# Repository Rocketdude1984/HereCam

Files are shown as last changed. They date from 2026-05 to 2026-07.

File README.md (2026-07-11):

# HereCam (WIP)
A camera for making yearly timelapses of a single room. Uses a Pi zero 2w, camera, and UPS hat. Inspired by the movie _Here_ (2024).

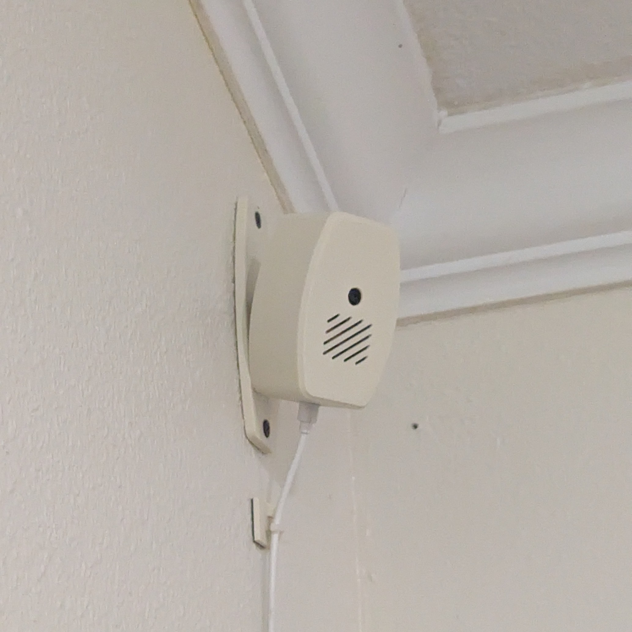
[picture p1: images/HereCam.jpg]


## Goals
- [x] Create a device that takes a picture at set intervals over the course of a year.
- [x] Store images on an SD card or SSD with easy removal.
- [x] Set up nightly automated backups to external server over wifi.
- [x] Be able to compile a years worth of images into a single timeplapse video
- [x] The timeplapse must have a reasonable play time (<1hr) and good quality.
- [ ] Must be able to operate without AC power for at least 12 hrs.
- [ ] Under $300 (2026 USD)

## Components
- Raspberry Pi Zero 2W - small form factor, wireless, enough processing power for timelapse compilation and image capture, and sd card slot.
- 75° Pi Camera module - FOV should be wide enough for being in the corner of a room, with IR filter.
- UPS hat - back-up power for when the device is unplugged, uses a lipo battery.
- SD card - capable of containing Pi OS and room for images, highly reliable card.
- Wall adapter - 5v slim form factor wall adapter
(see BOM for details of all components)

## Calculations

### 1. Length of Timelapse and number of images
   The first step was to find out how long I would want the timplapse to be and the framerate of the movie, which would also tell me the number of images that would be taken each year. I knew I did not want to capture images of every single hour, because the room I would be mounting the camera would have no one in it late at night (a living room). So I went with 20 hours per day (6am-2am). I also knew I wanted at least 24fps.
   
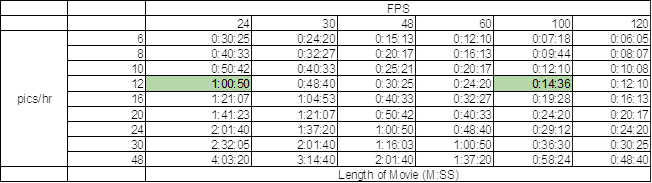
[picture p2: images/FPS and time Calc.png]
   

   I ended up liking two durations at 12 pics per hour (one image every 5 mins). This would give me a total of 87600 images/year. I liked the option of having a short timelapse (about 15 minutes and a longer at about 1 hour). The FPS of the short timelapse would be 100fps and the longer would be 24fps.
   
### 2. Storage size requirements
Now that I knew how many images I would have to store, I needed to calculate which resolution I would desire for a good quality video, yet not having a huge storage requirement. I was aiming for less than 256GB of images per year. I took pictures on my phone at 3 different resolutions and jpeg qualities. 1920x1080, 1920x1440, and 3840x2160 at 80%, 90%, and 100% (I ended up also trying 92% for the 3840x2160 resolution). I found that both the 1920x1080 and 1920x1440 resolutions did not look near crisp enough for my taste, so I stuck with the 3840x2160 resolution. JPEG compression somewhat works based on the actual image, so my test were done in about the expected positions that I would possibly mount the camera and then averaged together for a file average image size. The table below shows the final average values in KB for each image and in GB for the total 87600 images.

   

   All the 100% compression rates sizes were larger than I was wanting, but 90% and even 92% for the 3840x2160 was well under the 256GB I was wanting (the OS will eat up some of the SD card, will have to keep that in mind). I had at first picked the 90% compression, but ended up lowering it to 85% which images average 726KB, so about 61GB per year of images.

### 3. Runtime on Battery
Once I got the UPS hat and batteries in (a 1000mAh and 2000mAh), I did some ran a demo script that measures the power being used from the battery to run the pi. While idle the pi drew about 185mA from the battery and while taking a picture the pi drew about 400mA but only for about 2 seconds. Using these values I calculated the estimated runtime for the system. The 1000mAh battery would last about 6 hours while the 2000mAh would run about 11.8 hours. I then ran 2 tests to measure the actual runtime for each battery. For these test I ran a cron script to take an image every 5 minutes and name the file the number of the total images taken. This way I could moniter the battery voltage with the demo script and see when the voltage drops to 3.0 volts (voltage when BMS on the cell cuts off). I could then multiply the number of images taken by 5 minutes to get a total runtime. The calculated and actual values are below.

   

The 2000mAh lipo is still somewhat short of 12 hrs and this runtime will only decrease, but considering the size of the the device, I do not think I can increase the lipo much more. 

## Development
I designed and 3D printed several different housing and mounting systems for the camera. My first 2 designs used a mounting system that screwed into the corner of a room, but I later changed to a 2-axis mounting system that could mount on any way, just in case in the future I put the camera not in a corner. The later designs also included a vent for heat from the Pi.

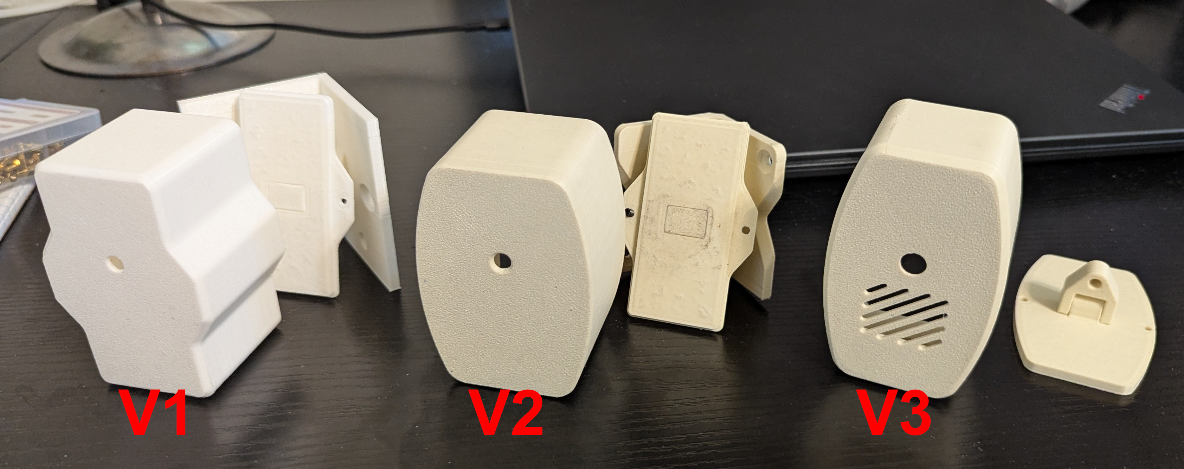
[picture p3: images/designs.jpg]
   

See the parts folder for 3D files.

## Construction

Two heat threaded inserts (2mm) and 2, 2mm socket head screws are used to mount the camera module in place. The pi/UPS modules are mounted with brass standoffs, and those standoffs are held in hexagonal pockets in the housing with JB weld. The lid to the housing is held in using 3mm heat threaded inserts and socket head screws. The mount uses 4mm socket head screws with nuts and washers to allow the camera to pivot on the 2 axes. The whole mount is fasten to the wall with regular 1-5/8" drywall screws. 

I had a lot of issues with the pogo pins of the UPS hat not aligning with the Pi's pads. To fix this I solderd the pads that contact the pogo connectors and this fixed all the issues. See the image below.

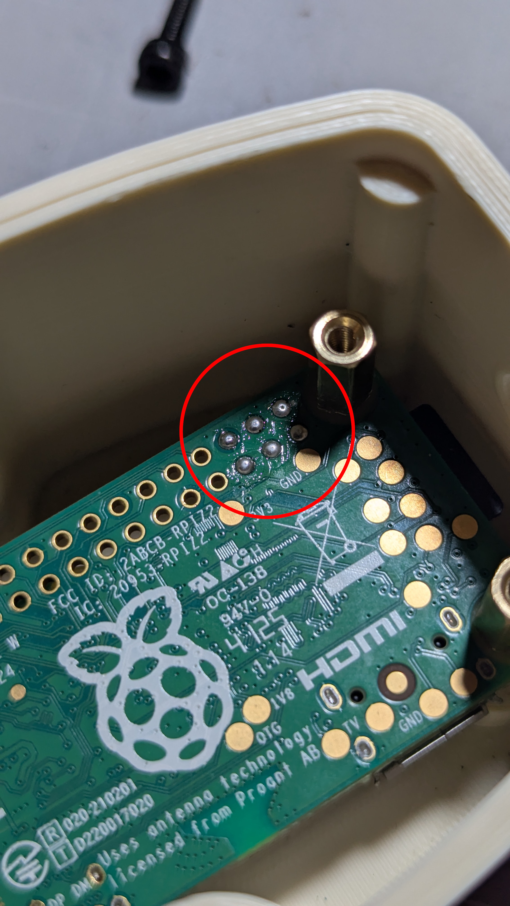
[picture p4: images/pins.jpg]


## Code

I first set up my homelab server as a network attached storage with samba share. and made it a permanent mount. This way I can send images to the server to actually view them for testing and as backup storage for the images/videos. 

For capturing the images I made a script called capture.sh (see the code folder). This script is run with Cron scheduler with the schedule of: */5 0,6-23 * * * /home/herecam/capture.sh
This captures an image every 5 minutes for the hours between 6am and midnight.

For backing up the images I used rsync to send the images to my mounted homelab with nightlyBackup.sh (see code folder). This script is run every night at 2 am, when pictures are not being taken: 0 2 * * * /home/herecam/nightlyBackup.sh

For monitoring the UPS (to see if AC power is lost) I modified the demo python script from waveshare for the hat, UPS_monitor.py (see code folder). The deme program already outputs the values for current in or out of the battery, voltage, and power drawn, so I just used the requests library to send my phone a ntfy notification for when the current draw is less than a set threshold (meaning no AC power) and then when power is restored it send another notification to let me know power is back. This script is made a service and run with systemd every 30 seconds.

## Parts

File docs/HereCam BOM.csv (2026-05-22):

Item | Cost | Shipping Cost | Description | Store | Link
CanaKit Raspberry Pi Zero 2 W Basic Kit | $49.99 | $0.00 | Pi zero 2W | Amazon | https://a.co/d/0bfg0yPq
Pi Camera Module 3 - Sony IMX708, 4608 — 2592 pixels, IR cut filter, autofocus | $25.00 | $0.00 | Camera | Seeed Studio | https://www.seeedstudio.com/Raspberry-Pi-Camera-3-p-5574.html
Uninterruptible Power Supply UPS HAT | $23.99 | $10.00 | UPS backup | Waveshare | https://www.waveshare.com/ups-hat-c.htm
SANDISK 256GB High Endurance Video microSDXC Card | $59.99 | $0.00 | SD card | Amazon | https://a.co/d/08b6umc9
EEMB Lithium Polymer Battery 3.7V 2000mAh 803465 (67x35mm) | $11.99 | $0.00 | Bigger Battery | Amazon | https://www.amazon.com/EEMB-Battery-2000mAh-Rechargeable-Connector/dp/B09DPP44GM
 | $170.96 | $10.00
Total Cost (shipping and tax (8.75%)) | $196.79

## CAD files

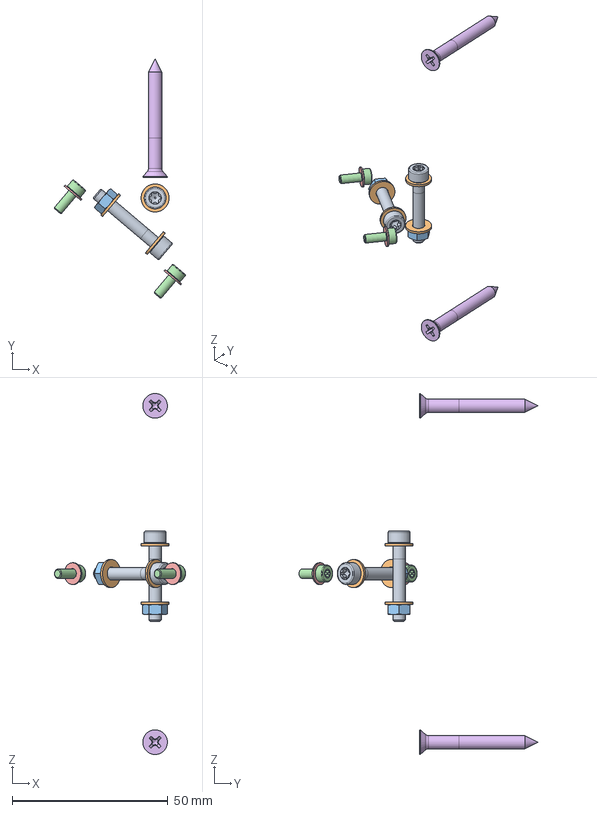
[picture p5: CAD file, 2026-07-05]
3D models/Assembly-v3.1.FCStd
42.1 x 76.8 x 115.9 mm
M4x25-Screw x 2
M4-Washer x 4
M4-Nut x 2
M3x8-Screw x 2
M3-Washer x 2
#8x1 1/2in-Screw x 2

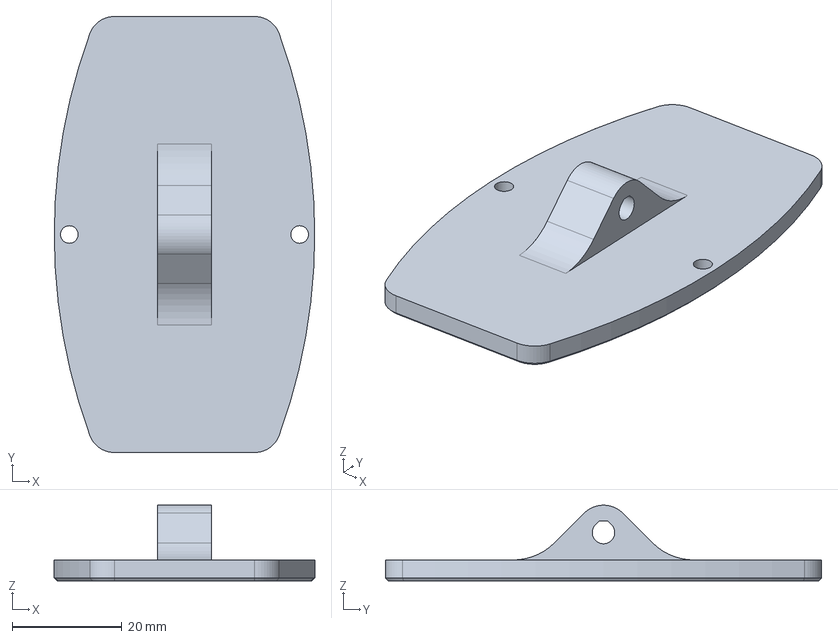
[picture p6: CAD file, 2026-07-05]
3D models/Lid-v3.FCStd
47.5 x 79.5 x 13.8 mm

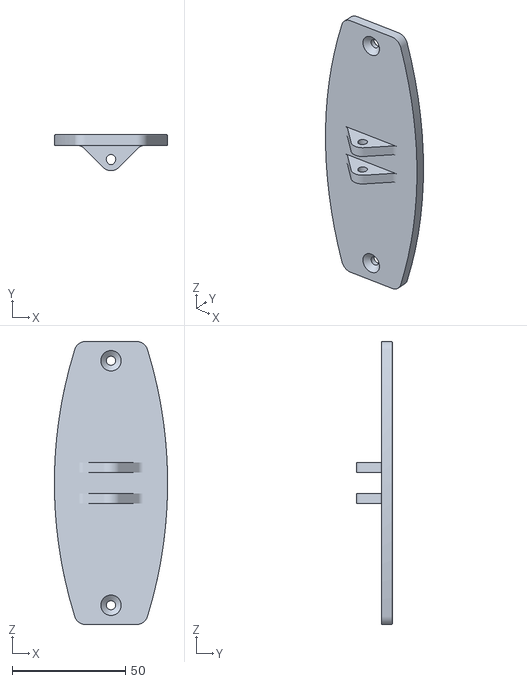
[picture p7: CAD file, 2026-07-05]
Parts/Holder-v3-Holder.stl
50.0 x 16.0 x 125.0

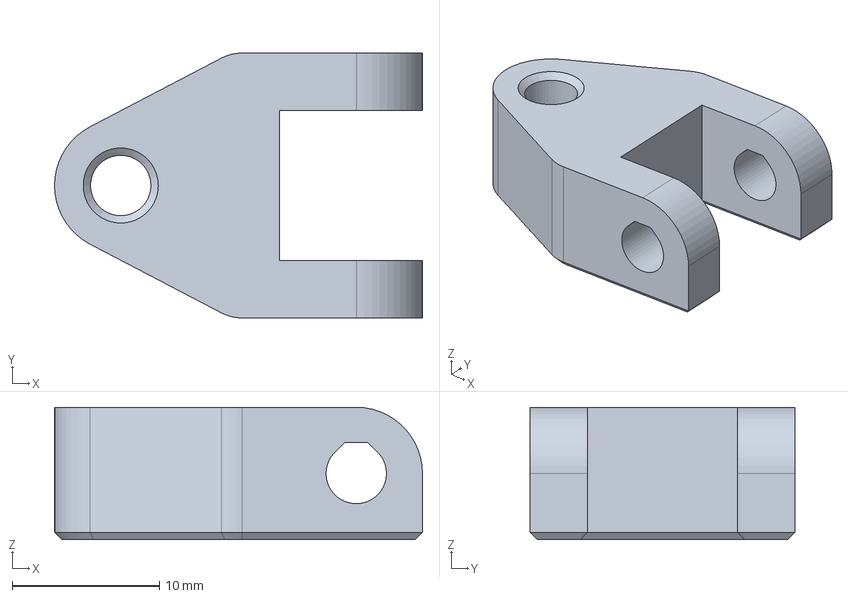
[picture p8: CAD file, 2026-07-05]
3D models/Link.FCStd
25.0 x 18.0 x 9.00 mm

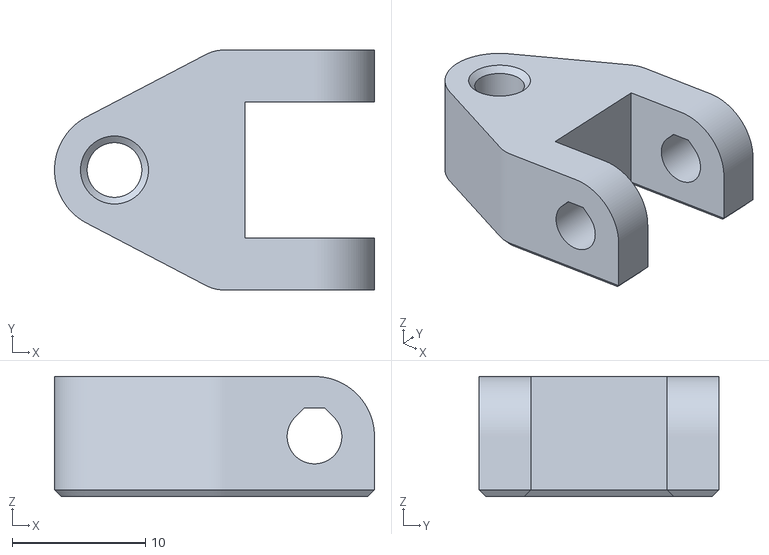
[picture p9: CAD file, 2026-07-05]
Parts/HereCam-v3-Link6mm.stl
24.0 x 18.0 x 9.00

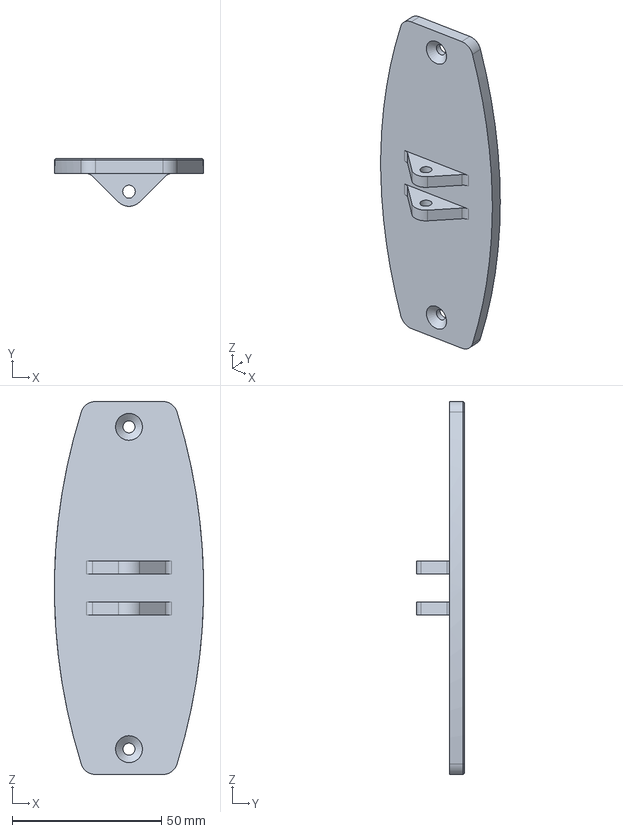
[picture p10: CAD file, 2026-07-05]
3D models/Holder-v3.FCStd
50.0 x 16.0 x 125.0 mm

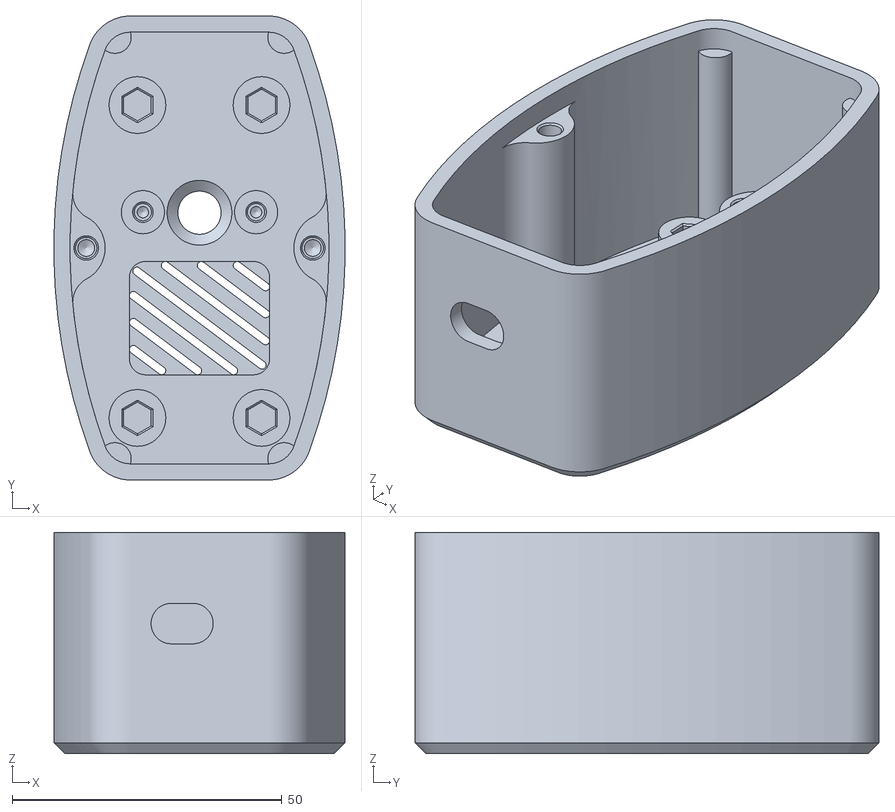
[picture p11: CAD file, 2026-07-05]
Parts/HereCam-v3-Case.stl
53.9 x 86.0 x 41.0

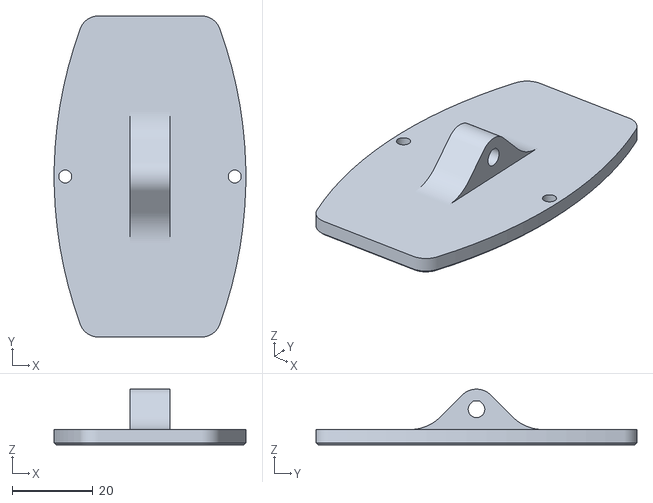
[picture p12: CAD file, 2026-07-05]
Parts/HereCam-v3-Lid.stl
47.4 x 79.5 x 13.8

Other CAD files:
3D models/HereCam-v3.FCStd
Parts/HereCam-v3-Link8mm.stl

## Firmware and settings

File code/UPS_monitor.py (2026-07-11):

import smbus
import time
import requests
import socket

NTFY_URL = "https://ntfy.sh/HereCam"
CURRENT_THRESHOLD_A = -0.1

# Config Register (R/W)
_REG_CONFIG                 = 0x00
# SHUNT VOLTAGE REGISTER (R)
_REG_SHUNTVOLTAGE           = 0x01

# BUS VOLTAGE REGISTER (R)
_REG_BUSVOLTAGE             = 0x02

# POWER REGISTER (R)
_REG_POWER                  = 0x03

# CURRENT REGISTER (R)
_REG_CURRENT                = 0x04

# CALIBRATION REGISTER (R/W)
_REG_CALIBRATION            = 0x05

class BusVoltageRange:
    """Constants for ``bus_voltage_range``"""
    RANGE_16V               = 0x00      # set bus voltage range to 16V
    RANGE_32V               = 0x01      # set bus voltage range to 32V (default)

class Gain:
    """Constants for ``gain``"""
    DIV_1_40MV              = 0x00      # shunt prog. gain set to  1, 40 mV range
    DIV_2_80MV              = 0x01      # shunt prog. gain set to /2, 80 mV range
    DIV_4_160MV             = 0x02      # shunt prog. gain set to /4, 160 mV range
    DIV_8_320MV             = 0x03      # shunt prog. gain set to /8, 320 mV range

class ADCResolution:
    """Constants for ``bus_adc_resolution`` or ``shunt_adc_resolution``"""
    ADCRES_9BIT_1S          = 0x00      #  9bit,   1 sample,     84us
    ADCRES_10BIT_1S         = 0x01      # 10bit,   1 sample,    148us
    ADCRES_11BIT_1S         = 0x02      # 11 bit,  1 sample,    276us
    ADCRES_12BIT_1S         = 0x03      # 12 bit,  1 sample,    532us
    ADCRES_12BIT_2S         = 0x09      # 12 bit,  2 samples,  1.06ms
    ADCRES_12BIT_4S         = 0x0A      # 12 bit,  4 samples,  2.13ms
    ADCRES_12BIT_8S         = 0x0B      # 12bit,   8 samples,  4.26ms
    ADCRES_12BIT_16S        = 0x0C      # 12bit,  16 samples,  8.51ms
    ADCRES_12BIT_32S        = 0x0D      # 12bit,  32 samples, 17.02ms
    ADCRES_12BIT_64S        = 0x0E      # 12bit,  64 samples, 34.05ms
    ADCRES_12BIT_128S       = 0x0F      # 12bit, 128 samples, 68.10ms

class Mode:
    """Constants for ``mode``"""
    POWERDOW                = 0x00      # power down
    SVOLT_TRIGGERED         = 0x01      # shunt voltage triggered
    BVOLT_TRIGGERED         = 0x02      # bus voltage triggered
    SANDBVOLT_TRIGGERED     = 0x03      # shunt and bus voltage triggered
    ADCOFF                  = 0x04      # ADC off
    SVOLT_CONTINUOUS        = 0x05      # shunt voltage continuous
    BVOLT_CONTINUOUS        = 0x06      # bus voltage continuous
    SANDBVOLT_CONTINUOUS    = 0x07      # shunt and bus voltage continuous


class INA219:
    def __init__(self, i2c_bus=1, addr=0x40):
        self.bus = smbus.SMBus(i2c_bus);
        self.addr = addr

        # Set chip to known config values to start
        self._cal_value = 0
        self._current_lsb = 0
        self._power_lsb = 0
        self.set_calibration_16V_5A()

    def read(self,address):
        data = self.bus.read_i2c_block_data(self.addr, address, 2)
        return ((data[0] * 256 ) + data[1])

    def write(self,address,data):
        temp = [0,0]
        temp[1] = data & 0xFF
        temp[0] =(data & 0xFF00) >> 8
        self.bus.write_i2c_block_data(self.addr,address,temp)

    def set_calibration_16V_5A(self):
        """Configures to INA219 to be able to measure up to 16V and 5A of current. Counter
           overflow occurs at 16A.
           ..note :: These calculations assume a 0.01 shunt ohm resistor is present
        """
        # By default we use a pretty huge range for the input voltage,
        # which probably isn't the most appropriate choice for system
        # that don't use a lot of power.  But all of the calculations
        # are shown below if you want to change the settings.  You will
        # also need to change any relevant register settings, such as
        # setting the VBUS_MAX to 16V instead of 32V, etc.

        # VBUS_MAX = 16V             (Assumes 16V, can also be set to 32V)
        # VSHUNT_MAX = 0.08          (Assumes Gain 2, 80mV, can also be 0.32, 0.16, 0.04)
        # RSHUNT = 0.01               (Resistor value in ohms)

        # 1. Determine max possible current
        # MaxPossible_I = VSHUNT_MAX / RSHUNT
        # MaxPossible_I = 8.0A

        # 2. Determine max expected current
        # MaxExpected_I = 5.0A

        # 3. Calculate possible range of LSBs (Min = 15-bit, Max = 12-bit)
        # MinimumLSB = MaxExpected_I/32767
        # MinimumLSB = 0.0001529              (61uA per bit)
        # MaximumLSB = MaxExpected_I/4096
        # MaximumLSB = 0,0012207              (488uA per bit)

        # 4. Choose an LSB between the min and max values
        #    (Preferrably a roundish number close to MinLSB)
        # CurrentLSB = 0.00016 (uA per bit)
        self._current_lsb = 0.1524  # Current LSB = 100uA per bit

        # 5. Compute the calibration register
        # Cal = trunc (0.04096 / (Current_LSB * RSHUNT))
        # Cal = 13434 (0x347a)

        self._cal_value = 26868

        # 6. Calculate the power LSB
        # PowerLSB = 20 * CurrentLSB
        # PowerLSB = 0.002 (2mW per bit)
        self._power_lsb = 0.003048  # Power LSB = 2mW per bit

        # 7. Compute the maximum current and shunt voltage values before overflow
        #
        # Max_Current = Current_LSB * 32767
        # Max_Current = 3.2767A before overflow
        #
        # If Max_Current > Max_Possible_I then
        #    Max_Current_Before_Overflow = MaxPossible_I
        # Else
        #    Max_Current_Before_Overflow = Max_Current
        # End If
        #
        # Max_ShuntVoltage = Max_Current_Before_Overflow * RSHUNT
        # Max_ShuntVoltage = 0.32V
        #
        # If Max_ShuntVoltage >= VSHUNT_MAX
        #    Max_ShuntVoltage_Before_Overflow = VSHUNT_MAX
        # Else
        #    Max_ShuntVoltage_Before_Overflow = Max_ShuntVoltage
        # End If

        # 8. Compute the Maximum Power
        # MaximumPower = Max_Current_Before_Overflow * VBUS_MAX
        # MaximumPower = 3.2 * 32V
        # MaximumPower = 102.4W

        # Set Calibration register to 'Cal' calculated above
        self.write(_REG_CALIBRATION,self._cal_value)

        # Set Config register to take into account the settings above
        self.bus_voltage_range = BusVoltageRange.RANGE_16V
        self.gain = Gain.DIV_2_80MV
        self.bus_adc_resolution = ADCResolution.ADCRES_12BIT_32S
        self.shunt_adc_resolution = ADCResolution.ADCRES_12BIT_32S
        self.mode = Mode.SANDBVOLT_CONTINUOUS
        self.config = self.bus_voltage_range << 13 | \
                      self.gain << 11 | \
                      self.bus_adc_resolution << 7 | \
                      self.shunt_adc_resolution << 3 | \
                      self.mode
        self.write(_REG_CONFIG,self.config)

    def getShuntVoltage_mV(self):
        self.write(_REG_CALIBRATION,self._cal_value)
        value = self.read(_REG_SHUNTVOLTAGE)
        if value > 32767:
            value -= 65535
        return value * 0.01

    def getBusVoltage_V(self):
        self.write(_REG_CALIBRATION,self._cal_value)
        self.read(_REG_BUSVOLTAGE)
        return (self.read(_REG_BUSVOLTAGE) >> 3) * 0.004

    def getCurrent_mA(self):
        value = self.read(_REG_CURRENT)
        if value > 32767:
            value -= 65535
        return value * self._current_lsb

    def getPower_W(self):
        self.write(_REG_CALIBRATION,self._cal_value)
        value = self.read(_REG_POWER)
        if value > 32767:
            value -= 65535
        return value * self._power_lsb

def is_connected(host="ntfy.sh", port=443, timeout=3):
    # check if internet is reachable (not local wifi only)
    try:
        socket.setdefaulttimeout(timeout)
        socket.socket(socket.AF_INET, socket.SOCK_STREAM).connect((host, port))
        return True
    except OSError:
        return False

def send_ntfy(message, title="HereCam Alert", priority="high", tags="warning"):
    try:
        requests.post(
            NTFY_URL,
            data=message.encode("utf-8"),
            headers={
                "Title": title,
                "Priority": priority,
                "Tags": tags
            },
            timeout=5
        )
        return True
    except requests.exceptions.RequestException as e:
        print(f"Failed to send NTFY notification: {e}")
        return False

if __name__=='__main__':

    # Create an INA219 instance.
    ina219 = INA219(addr=0x43)
    is_below_threshold = False
    pending_notification = None

    while True:
        bus_voltage = ina219.getBusVoltage_V()             # voltage on V- (load side)
        shunt_voltage = ina219.getShuntVoltage_mV() / 1000 # voltage between V+ and V- across the shunt
        current = ina219.getCurrent_mA()                   # current in mA
        current_A = current / 1000
        power = ina219.getPower_W()                        # power in W
        p = (bus_voltage - 3)/1.2*100
        if(p > 100):p = 100
        if(p < 0):p = 0

        # INA219 measure bus voltage on the load side. So PSU voltage = bus_voltage + shunt_voltage
        print("PSU Voltage:   {:6.3f} V".format(bus_voltage + shunt_voltage))
        print("Shunt Voltage: {:9.6f} V".format(shunt_voltage))
        print("Load Voltage:  {:6.3f} V".format(bus_voltage))
        print("Current:       {:6.3f} A".format(current/1000))
        print("Power:         {:6.3f} W".format(power))
        print("Percent:       {:3.1f}%".format(p))
        print("")

      # check if current is being drawn from the battery
        currently_below = current_A < CURRENT_THRESHOLD_A

      # if current is being drawn then AC must be lost
        if currently_below and not is_below_threshold:
            pending_notification = (
                f"Battery: {p:1f}%, Voltage: {bus_voltage:.3f} V",
                "HereCam: AC POWER LOST",
                "battery,warning"
            )
          # if current is less than threshold than power is being supplied to the battery
        elif not currently_below and is_below_threshold:
            pending_notification = (
                f"Battery: {p:.1f}%, Voltage: {bus_voltage:.3f} V",
                "HereCam: Power Restored",
                "battery,white_check_mark"
            )

        is_below_threshold = currently_below

        # try to flush any pending notifications
        if pending_notification is not None:
            if is_connected():
                message, title, tags = pending_notification
                if send_ntfy(message, title=title, tags=tags):
                    pending_notification = None # sent successfully
            else:
                print("No network - notification queued")

        time.sleep(30)

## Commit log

2026-05-18 Calculations
    These are the calculations used for finding framerate, number of images, resolution, and required storage size.
    [HereCam Calculations.xlsx]
2026-05-18 BOM upload
    [HereCam BOM.csv]
2026-05-22 Updating BOM
    [HereCam BOM.csv]
2026-06-03 Update README with UPS hat and battery runtime info
    Added details about UPS hat and battery performance.
2026-06-05 Battery Calculation
2026-06-05 Include battery runtime image in README
    Added an image to illustrate battery runtime results.
2026-07-05 Revise image compression and battery usage information
    Updated compression rate for image storage and adjusted battery power consumption details.
2026-07-05 Stl Upload
    [HereCam-v3-Case.stl, HereCam-v3-Lid.stl, HereCam-v3-Link6mm.stl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]
2026-07-05 3D models upload
    [Assembly-v3.1.FCStd, HereCam-v3.FCStd, Holder-v3.FCStd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]
